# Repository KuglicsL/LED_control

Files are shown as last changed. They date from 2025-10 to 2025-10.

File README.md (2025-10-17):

# PWM & ARGB LED controller
ESP32 based controller for high-current PWM dimming and long-distance addressable LED driving
# Features
- 4x 12V fault-protected differential output digital channels for addressable LED strips
- 4x 30A 0-26V open-drain PWM channels for RGB(W) or single colour LED strips
- 4x isolated optocoupler inputs (0-50V) in two groups
- Onboard programmer using CP2102N USB-UART bridge
- Fused connections on all output power ports - ATO/ATC fuse holders
- Two pinheaders for analog inputs
- Small outline - 100x100mm
- Optional TVS diodes when assembled using cheaper transceivers
- Compatible with [the WLED project](https://kno.wled.ge/)
- You can find the gerbers, BOM, and PnP files in the Outputs folder if you want to manufacture your own!
  
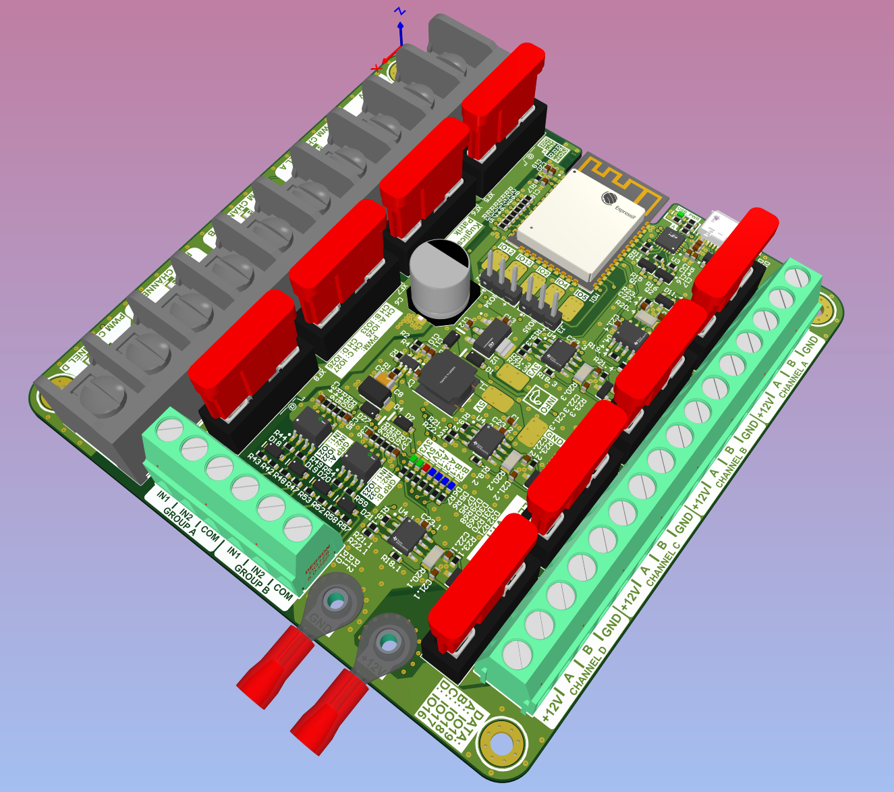
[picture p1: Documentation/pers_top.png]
PCB render


## PWM channels
The 4 independent PWM channels are open-drain outputs tested at 30A load. With adequate cooling, it can handle more. The FETs have TVS diodes, snubbers and flyback diodes protecting them.
## Digital channels
The 4 digital channels use THVD2450 transceivers for reliable long-distance addressable LED control. You can solder the in-line [receiver module](https://github.com/KuglicsL/Differential_receiver) to the LED strip at the first pixel.

## Limitations
The 12V input is routed to the digital channels, and the 24V input is for the PWM LED strips (voltage range 0-26V).
The control works from both the 12V and 24V inputs, however it needs the 12V input for the PWM gate drivers. **Without +12V connected, the PWM will not work.**

The differential outputs need a [receiver module](https://github.com/KuglicsL/Differential_receiver) on the LED side.

When using multiple channels at maximum current, the board probably needs cooling. I haven't got the time to test for exact numbers.

The USB-UART bridge IC needs to be configured to toggle the RX/TX leds - this is done with Silicon Labs' own tool. The whole USB-UART section could be replaced with a CH340 alternative for lower cost, but I wanted to use parts readily available from EU/NA distributors.

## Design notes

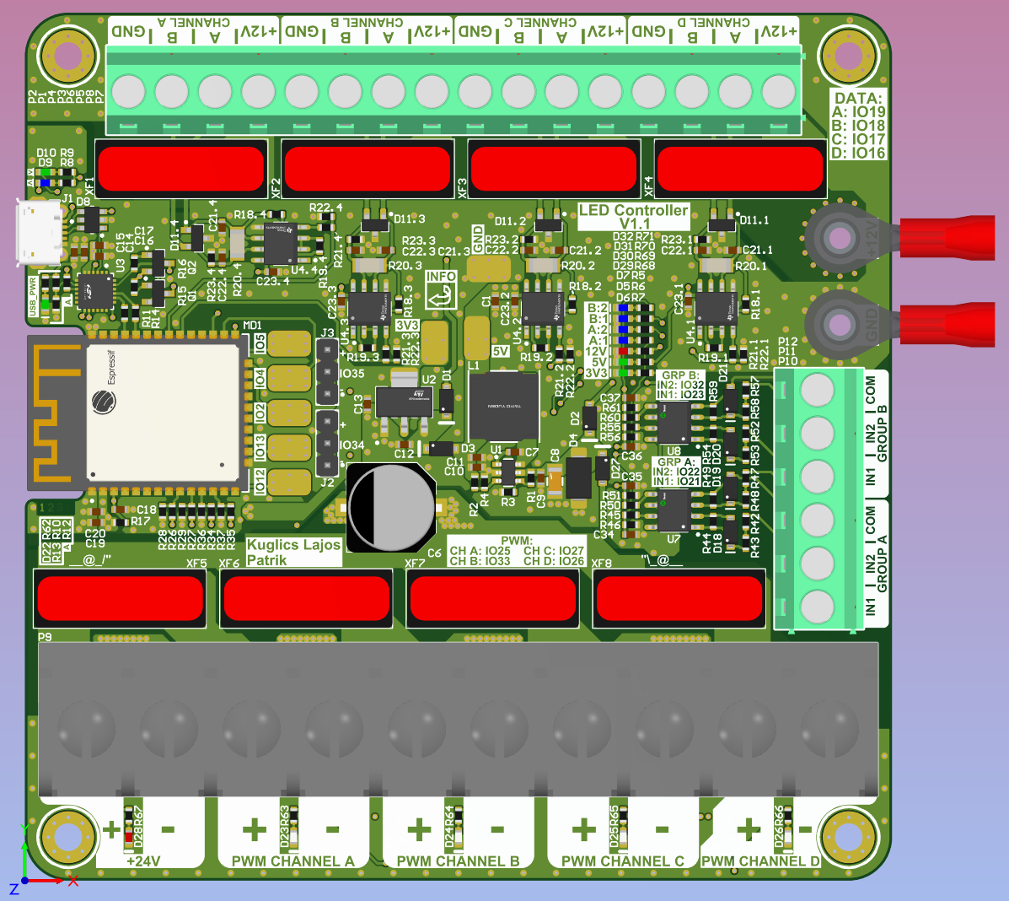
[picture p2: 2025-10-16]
Documentation/orth_front.png

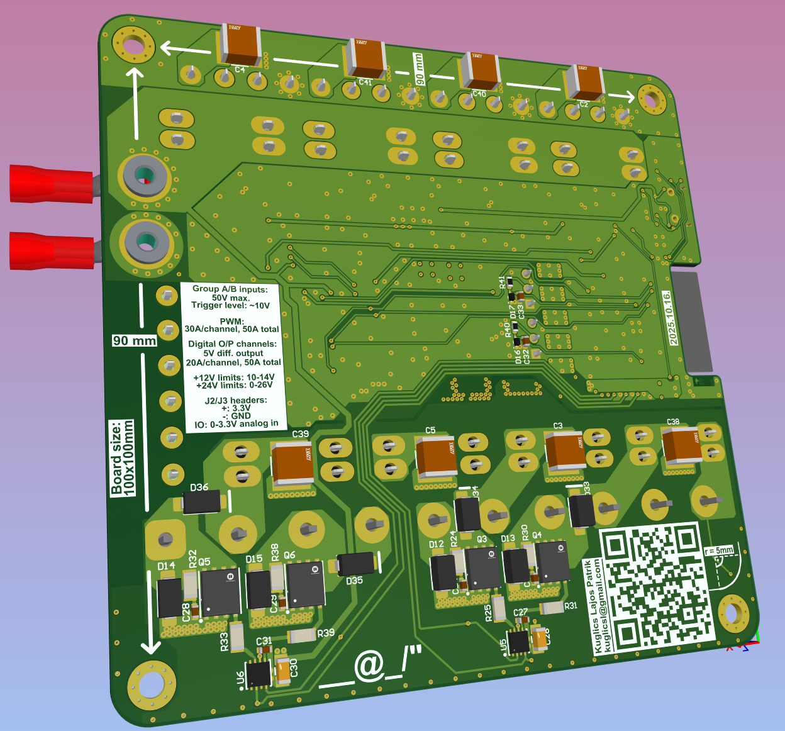
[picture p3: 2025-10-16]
Documentation/pers_back.png

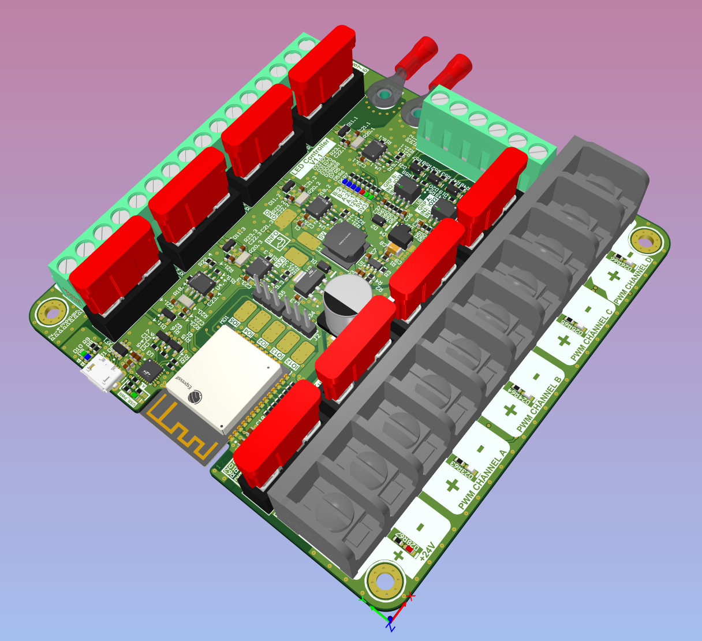
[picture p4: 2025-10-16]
Documentation/pers_bot.png

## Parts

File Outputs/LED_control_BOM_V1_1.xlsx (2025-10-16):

Comment | Description | Designator | Footprint | Pins | Quantity
ESP32-WROOM-32E (4MB) | RX TXRX MOD WIFI TRACE ANT SMD | MD1 | FP-ESP32-WROOM-32E_4MB-MFG | 39 | 1
CP2102N-A02-GQFN24 | IC USB TO UART BRIDGE QFN24 | U3 | FP-CP2102N-A02-GQFN24-MFG | 25 | 1
1050170001 | USB Connector, 5 Contact(s), Female, Right Angle, Surface Mount Terminal, Detent, Receptacle | J1 | USB-MICRO-B_V | 11 | 1
6PCV-10-006 | Barrier Strip Terminal Block, 25A, 1 Row(s), 1 Deck(s) | P9 | 6PCV-05-006-Footprint-1 | 10 | 1
IX4427MTR | 2 Channel Gate Driver IC, 4.5-30V, DFN-8 | U5, U6 | QFN65P300X300X85_HS-9N | 9 | 2
MOCD217M | Transistor Output Optocoupler, 2-Element, 2500V Isolation | U7, U8 | FP-751DZ-IPC_B | 8 | 2
THVD2450DR | Line Transceiver, 1 Func, 1 Driver, 1 Rcvr, PDSO8 | U4.1, U4.2, U4.3, U4.4 | FP-D0008A-IPC_B | 8 | 4
LMR54406DBVR | Switching Regulator, Current-mode, 0.6A, 1265kHz Switching Freq-Max, PDSO6 | U1 | SOT23-6 | 6 | 1
USBLC6-2SC6 | Trans Voltage Suppressor Diode, 5V V(RWM), Unidirectional, 1 Element, Silicon | D8 | STM-SOT23-6L_V | 6 | 1
BSC010N04LS6ATMA1 | OptiMOS 6 power MOSFET, 1.4mΩ max, 40V, 40A ID | Q3, Q4, Q5, Q6 | FP-483AE-MFG | 5 | 4
3557-10 | Keystone 3557-10 fuse holder; 3557-2 in RED | XF1, XF2, XF3, XF4, XF5, XF6, XF7, XF8 | Keystone 3557-2 | 4 | 8
LDL1117S33R | Fixed Positive LDO Regulator, 3.3V, 0.6V Dropout, PDSO4 | U2 | FP-SOT223-0046067-IPC_B | 4 | 1
BSS123,215 | Small Signal Field-Effect Transistor, 0.15A I(D), 100V, 1-Element, N-Channel, Silicon, Metal-oxide Semiconductor FET | Q1, Q2 | SOT23-3 | 3 | 2
NUP3105LT1G | Trans Voltage Suppressor Diode, 350W, 32V V(RWM), Bidirectional, 2 Element, Silicon | D11.1, D11.2, D11.3, D11.4 | SOT23-3 | 3 | 4
Pinheader 1x3 | Pinheader 1x3 | J2, J3 | FP-90120-0123-MFG | 3 | 2
1µF/50V/X5R | 0603 capacitor | C12 | C0603 | 2 | 1
1k/1%/0603 | 0603 1% resistor, 100mW | R12, R40, R41 | R0603 | 2 | 3
1N4148W | Rectifier Diode, 1 Phase, 1 Element, 0.15A, 75V V(RRM), Silicon | D18, D19, D20, D21 | SOD-123 | 2 | 4
1nF/50V/X7R | 0603 capacitor | C24, C25, C28, C29 | C0603 | 2 | 4
2R2/1%/1206 | 1206 1% resistor, 250mW | R24, R25, R30, R31, R32, R33, R38, R39 | RESC3216X70X50NL05T20 | 2 | 8
10µF/10V/X5R | 0603 capacitor | C1, C10, C11, C13, C14, C17, C19 | C0603 | 2 | 7
10k/1%/0603 | 0603 1% resistor, 100mW | R3, R4, R6, R7, R8, R9, R15, R16, R17, R18.1, R18.2, R18.3, R18.4, R19.1, R19.2, R19.3, R19.4, R22.1, R22.2, R22.3, R22.4, R23.1, R23.2, R23.3, R23.4, R28, R29, R36, R37, R42, R43, R44, R46, R47, R48, R49, R51, R52, R53, R54, R56, R57, R58, R59, R61, R62, R63, R64, R65, R66, R68, R69, R70, R71 | R0603 | 2 | 54
10pF/50V/NPO | 0603 capacitor | C21.1, C21.2, C21.3, C21.4, C22.1, C22.2, C22.3, C22.4 | C0603 | 2 | 8
22k/1%/0603 | 0603 1% resistor, 100mW | R10 | R0603 | 2 | 1
53.6k/1%/0603 | 0603 1% resistor, 100mW | R1, R2, R5, R13, R67 | R0603 | 2 | 5
100/1%/0603 | 0603 1% resistor, 100mW | R11, R14, R21.1, R21.2, R21.3, R21.4, R26, R27, R34, R35, R45, R50, R55, R60 | R0603 | 2 | 14
100nF/50V/X7R | 0603 capacitor | C7, C9, C15, C16, C18, C20, C23.1, C23.2, C23.3, C23.4, C27, C31, C32, C33, C34, C35, C36, C37 | C0603 | 2 | 18
120R/1%/1206 | 1206 1% resistor, 250mW | R20.1, R20.2, R20.3, R20.4 | RESC3216X70X50NL05T20 | 2 | 4
22201C106MAT2A | Ceramic Capacitor, Multilayer, Ceramic, 100V, 20% +Tol, 20% -Tol, X7R, 15% TC, 10uF, Surface Mount, 2220 | C2, C3, C4, C5, C38, C39, C40, C41 | FP-2220-L_5_7_0_5-W_5_0_4-IPC_B | 2 | 8
CL31B105KBHNNNE | Ceramic Capacitor, Multilayer, Ceramic, 50V, 10% +Tol, 10% -Tol, X7R, 15% TC, 1uF, Surface Mount, 1206 | C26, C30 | CL31-1.6mm | 2 | 2
CL31B106KBHNNNE | Ceramic Capacitor, Multilayer, Ceramic, 50V, 10% +Tol, 10% -Tol, X7R, 15% TC, 10uF, Surface Mount, 1206 | C8 | CL31-1.6mm | 2 | 1
DG128-5.0-02P-14-00AH | Degson DG128-5.0-02P-14-00AH 2-Way PCB Screw Terminal Block 5.0mm Green | P1, P2, P3, P4, P5, P6, P7, P8, P10, P11, P12 | Sorkapocs_5mm | 2 | 11
EEH-ZA1V271P | Aluminum Electrolytic Capacitor, Polarized, Aluminum (solid Polymer), 35V, 20% +Tol, 20% -Tol, 270uF, Surface Mount, 4141 | C6 | CPOL_10x10.2MM | 2 | 1
ESD321DYAR | 0.9pF 3.6V ±30kV ESD protection diode with 6.8V 16A TLP clamping for USB 2.0 2-SOT-5X3 -55 to 150 | D16, D17 | SOD-523_ANODE_MARK | 2 | 2
KPG-1608ZGC | Single Color LED, Green, Water Clear, 1.2mm | D5, D6, D10, D22 | LED0603_GREEN | 2 | 4
LSQ976-NR-1 | Single Color LED, Super Red, Colorless Diffused, 1mm | D7, D28 | LED0603_RED | 2 | 2
LTW-C191TS5 | Single Color LED, White, 1.1mm, 45-180mcd, 2.7-3.15V Vf | D23, D24, D25, D26 | LED0603_WHITE | 2 | 4
MBR160 | Rectifier Diode, Schottky, 1 Element, 1A, 60V, Silicon, SOD-123 | D1, D2, D3, D27 | SOD-123 | 2 | 4
NRS8040T220MJGJ | General Purpose Inductor, 22uH, 20%, 1 Element, SMD, 3131 | L1 | FP-NR8040-H_4_0-MFG | 2 | 1
SK34SMA-3G | Rectifier Diode, Schottky, 1 Phase, 1 Element, 3A, 40V V(RRM), Silicon, DO-214AC (SMA) | D33, D34, D35, D36 | DO-214AC(SMA) | 2 | 4
SMAJ30CA | Trans Voltage Suppressor Diode, 400W, 30V V(RWM), Bidirectional, 1 Element, Silicon, DO-214AC | D4, D12, D13, D14, D15 | DO-214AC(SMA) | 2 | 5
SR190BC-B4-1BJ | 0603 blue LED, 200-400mcd, 3.2V@20mA | D9, D29, D30, D31, D32 | LED0603_BLUE | 2 | 5
9775031360R | WA-SMSR SMT Steel Spacer Reverse, M3 x 3.1mm | MP3, MP6 | 9775031360 | 1 | 2

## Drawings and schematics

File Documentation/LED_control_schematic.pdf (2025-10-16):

# USB_Programmer.SchDoc IO⁰ EN CP_RX CP_TX

# P1 DG¹²⁸⁻⁵.0⁻02P⁻¹⁴⁻⁰⁰AH 12

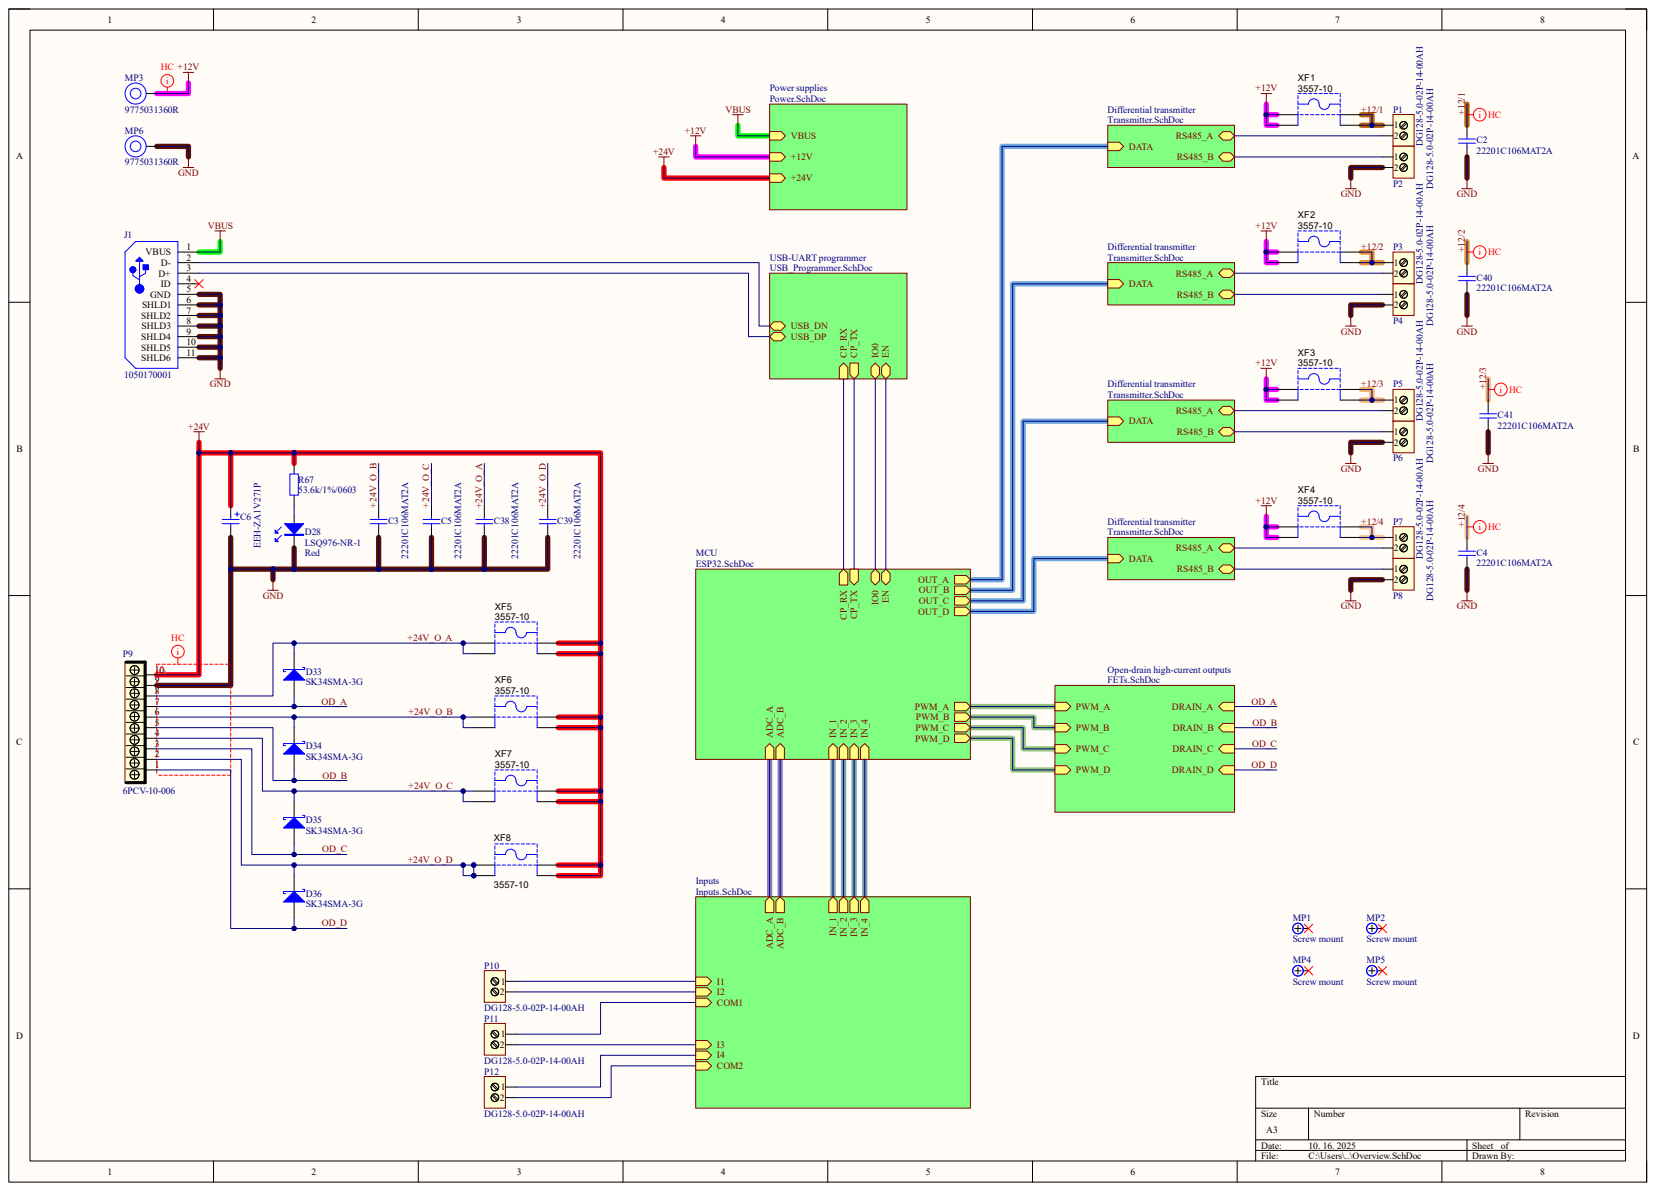
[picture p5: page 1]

Open-drain high-current outputs
FETs.SchDoc

## Ven_min = 7.0V

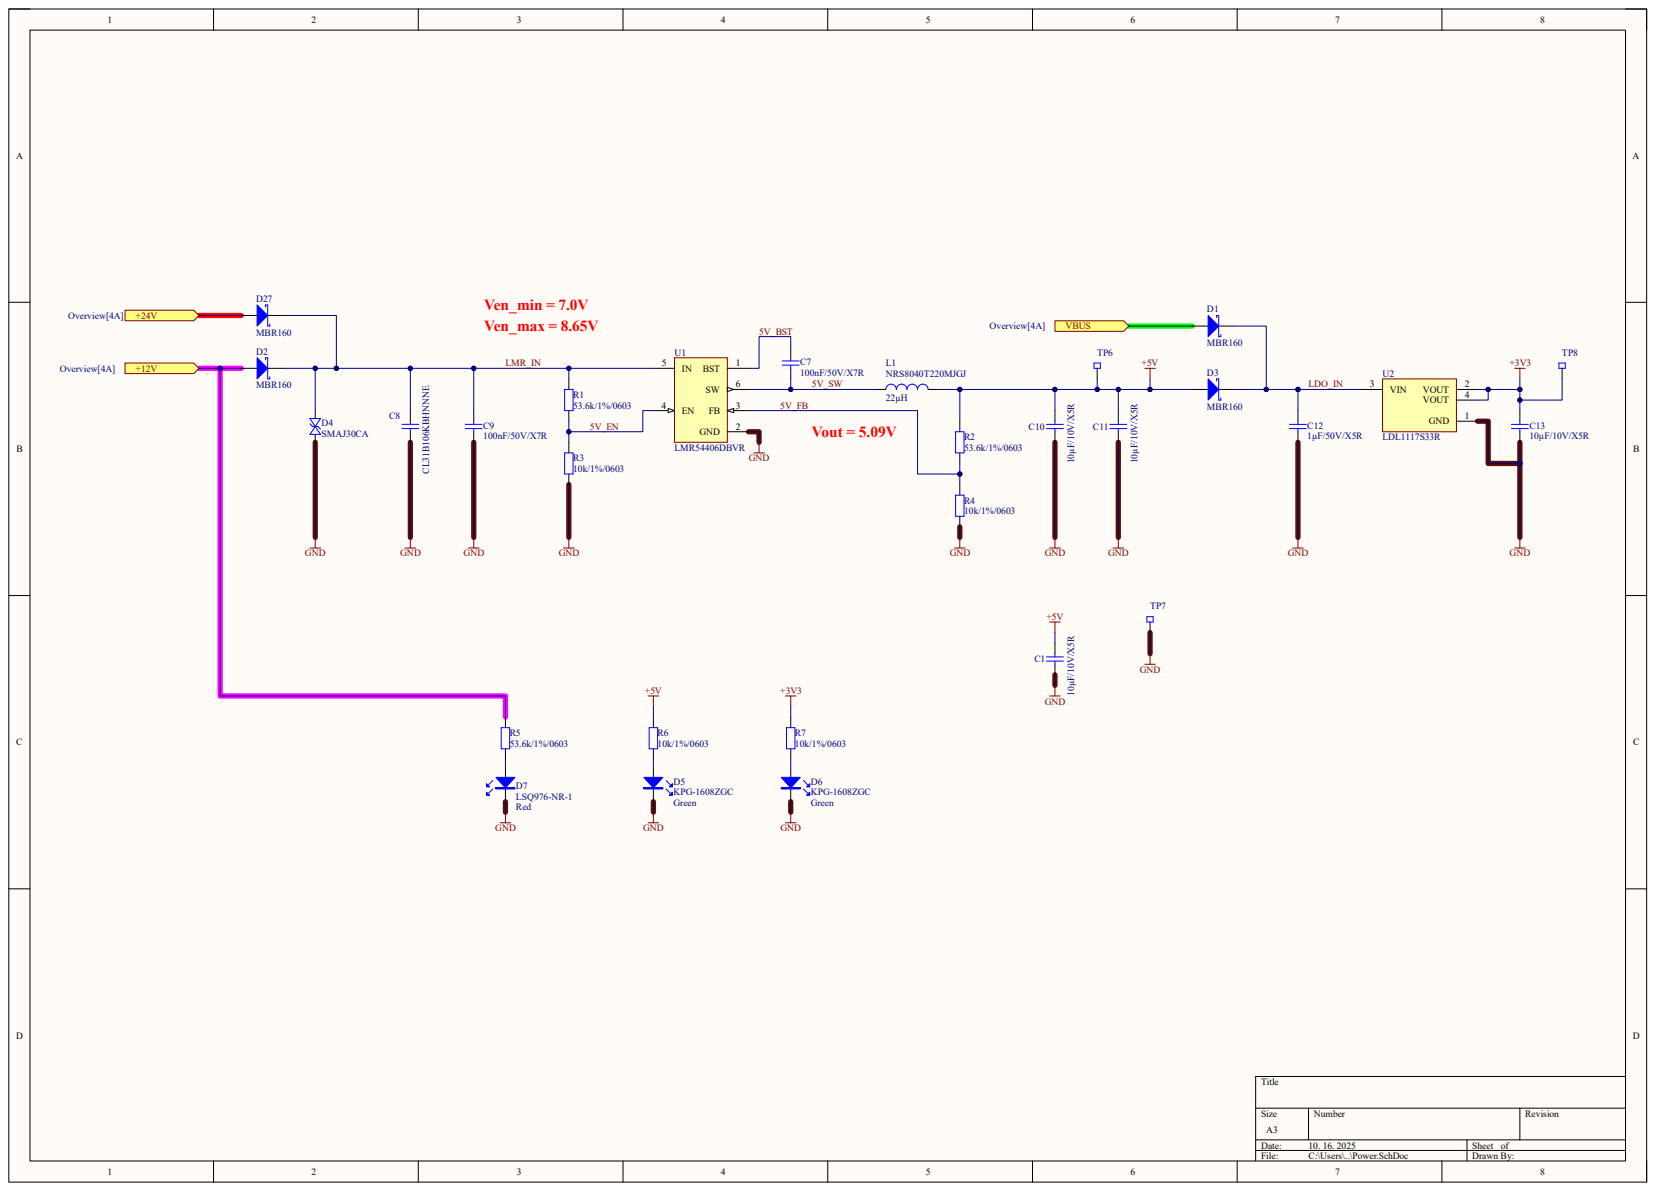
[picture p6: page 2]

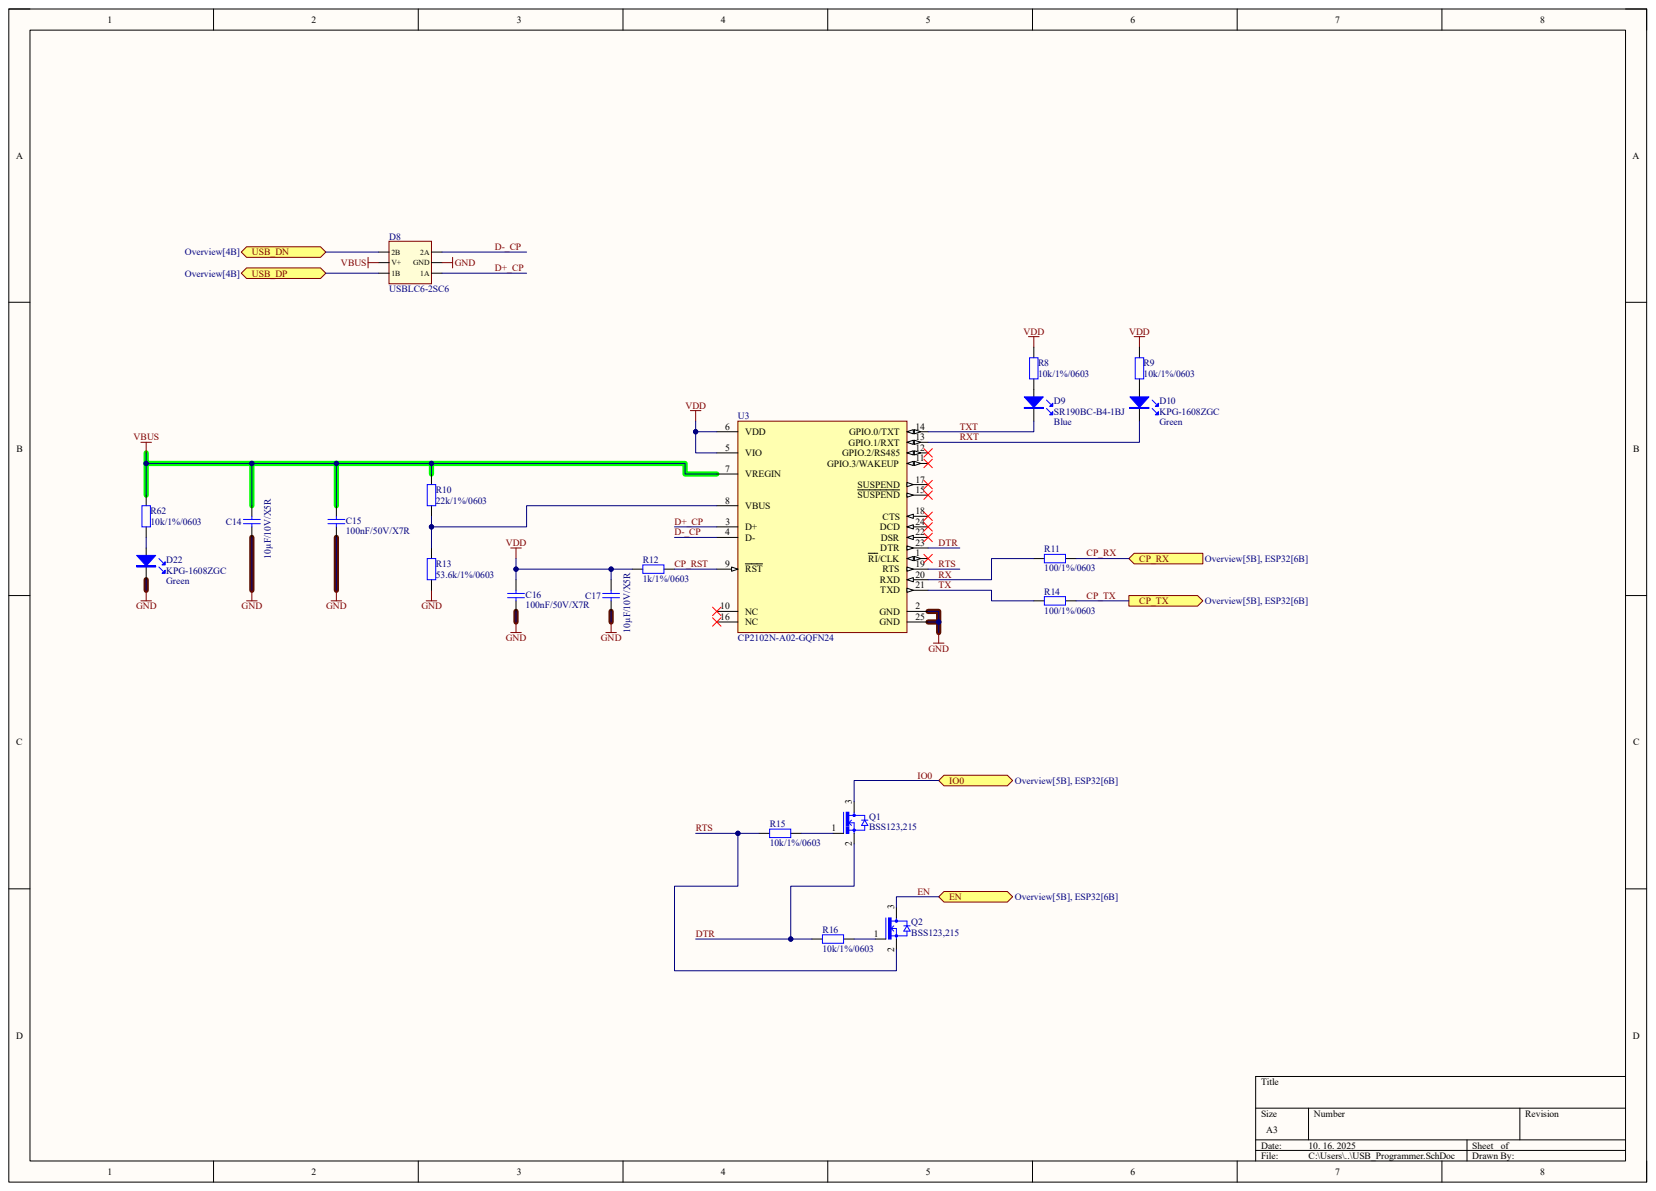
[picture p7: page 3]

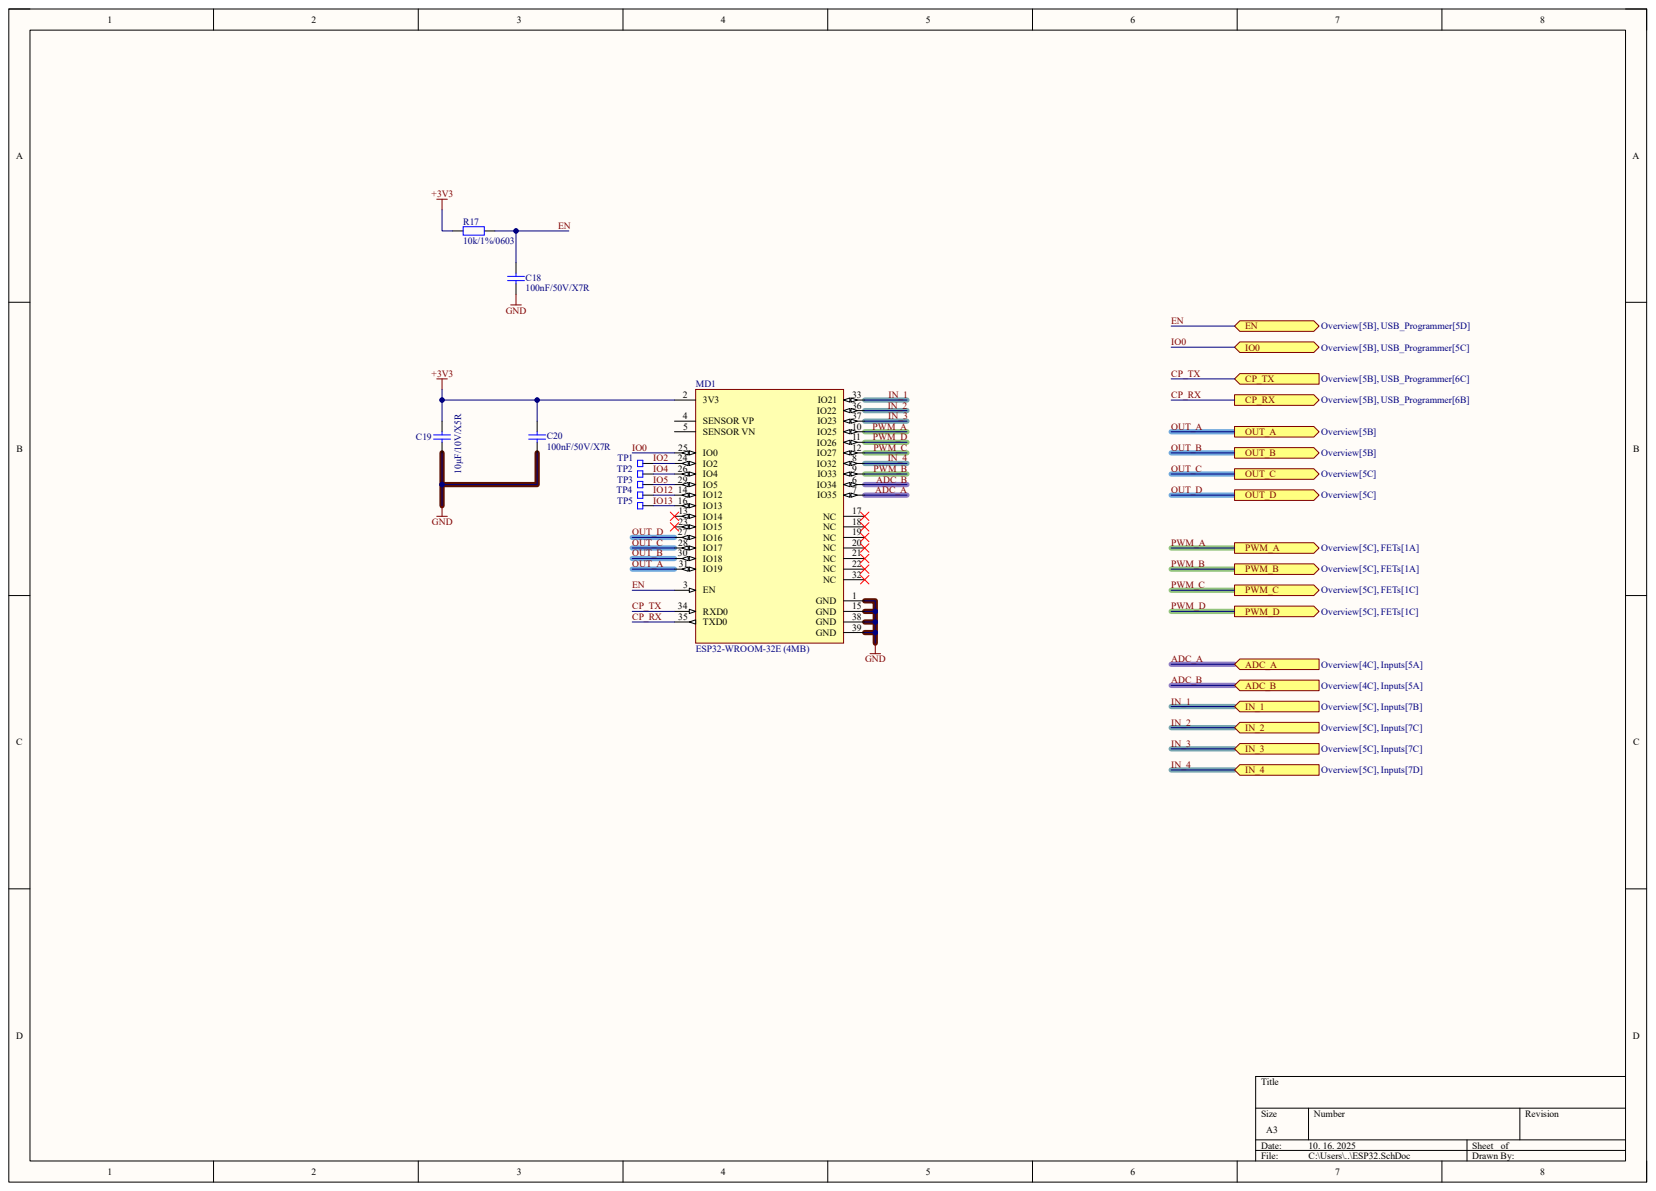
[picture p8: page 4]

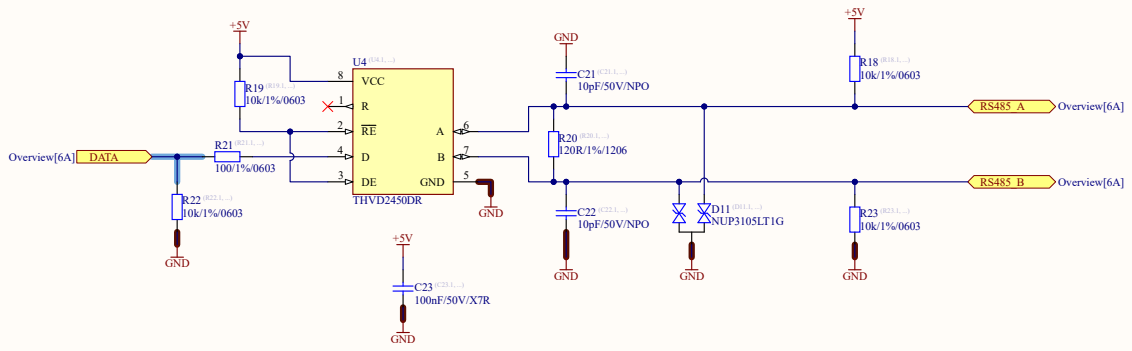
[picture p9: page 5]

A A

### INA 2

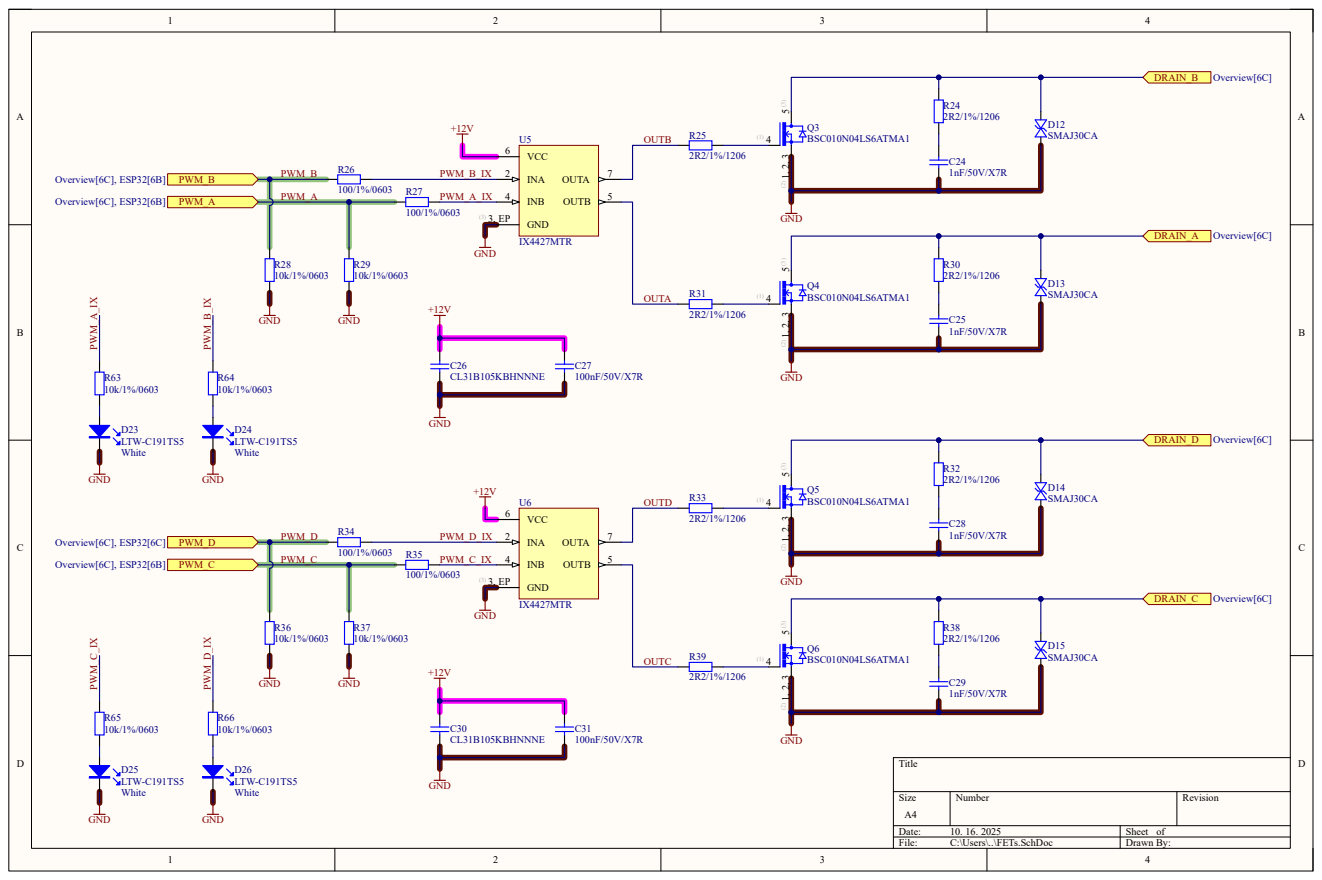
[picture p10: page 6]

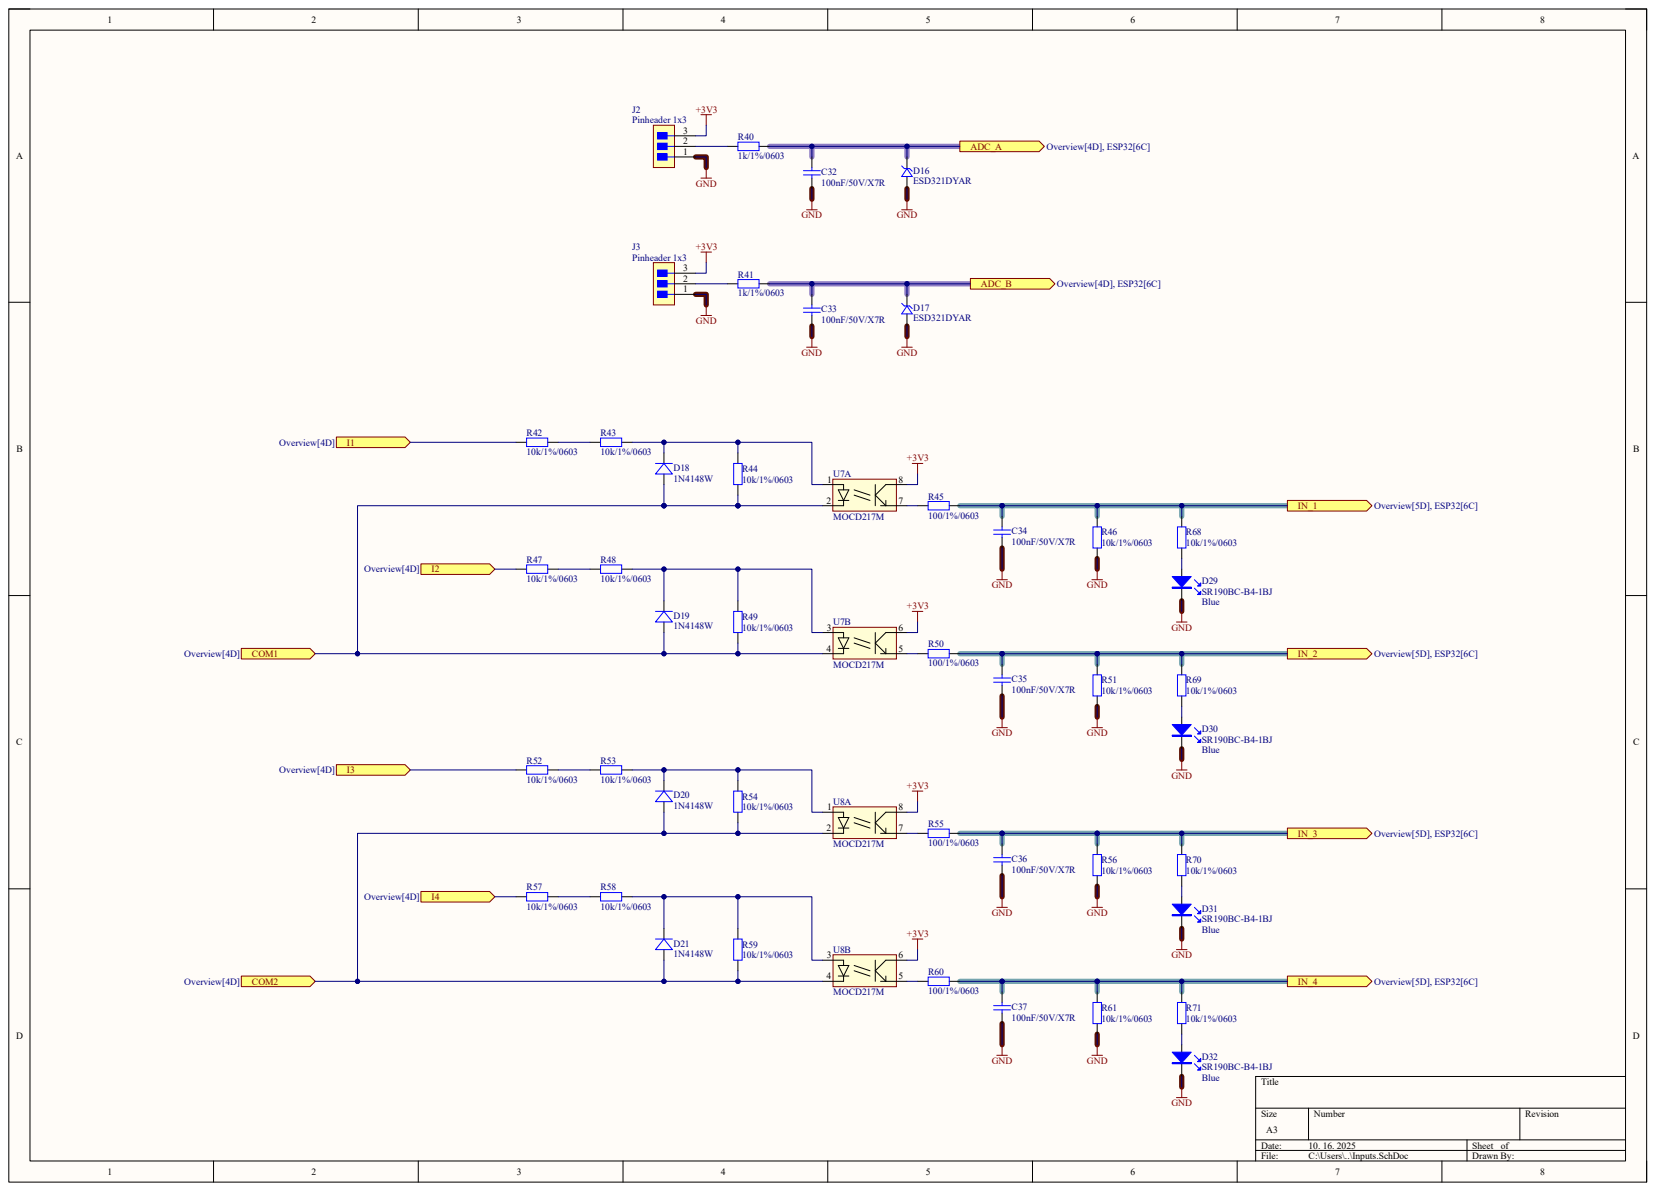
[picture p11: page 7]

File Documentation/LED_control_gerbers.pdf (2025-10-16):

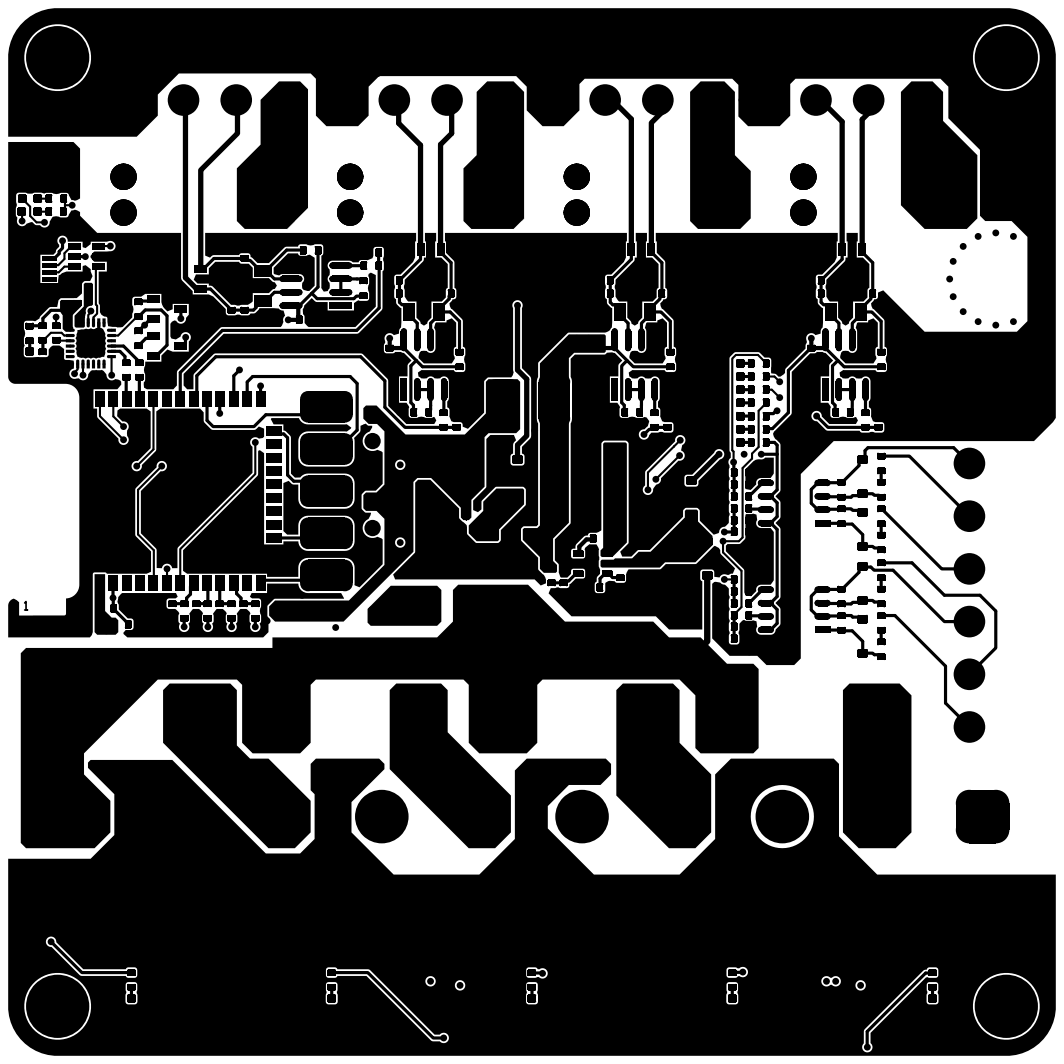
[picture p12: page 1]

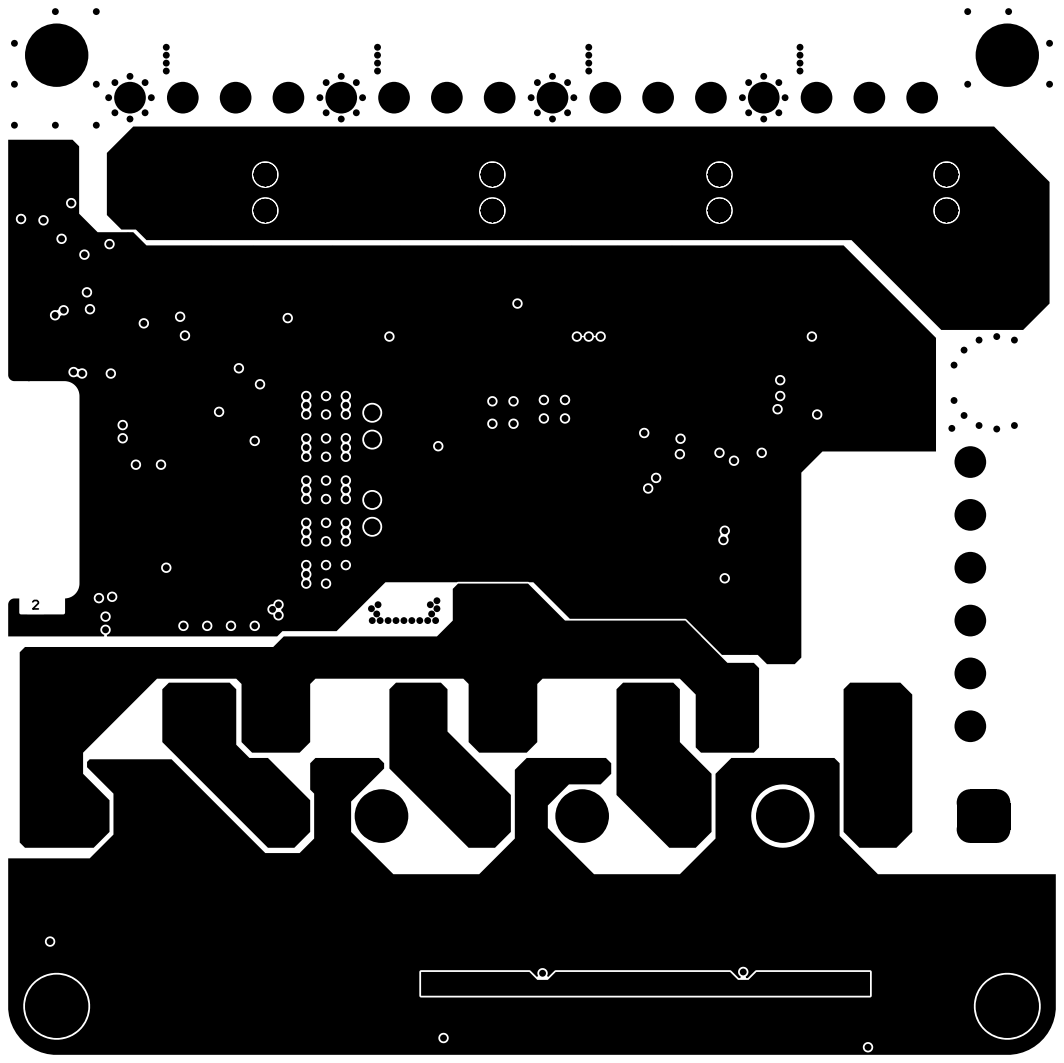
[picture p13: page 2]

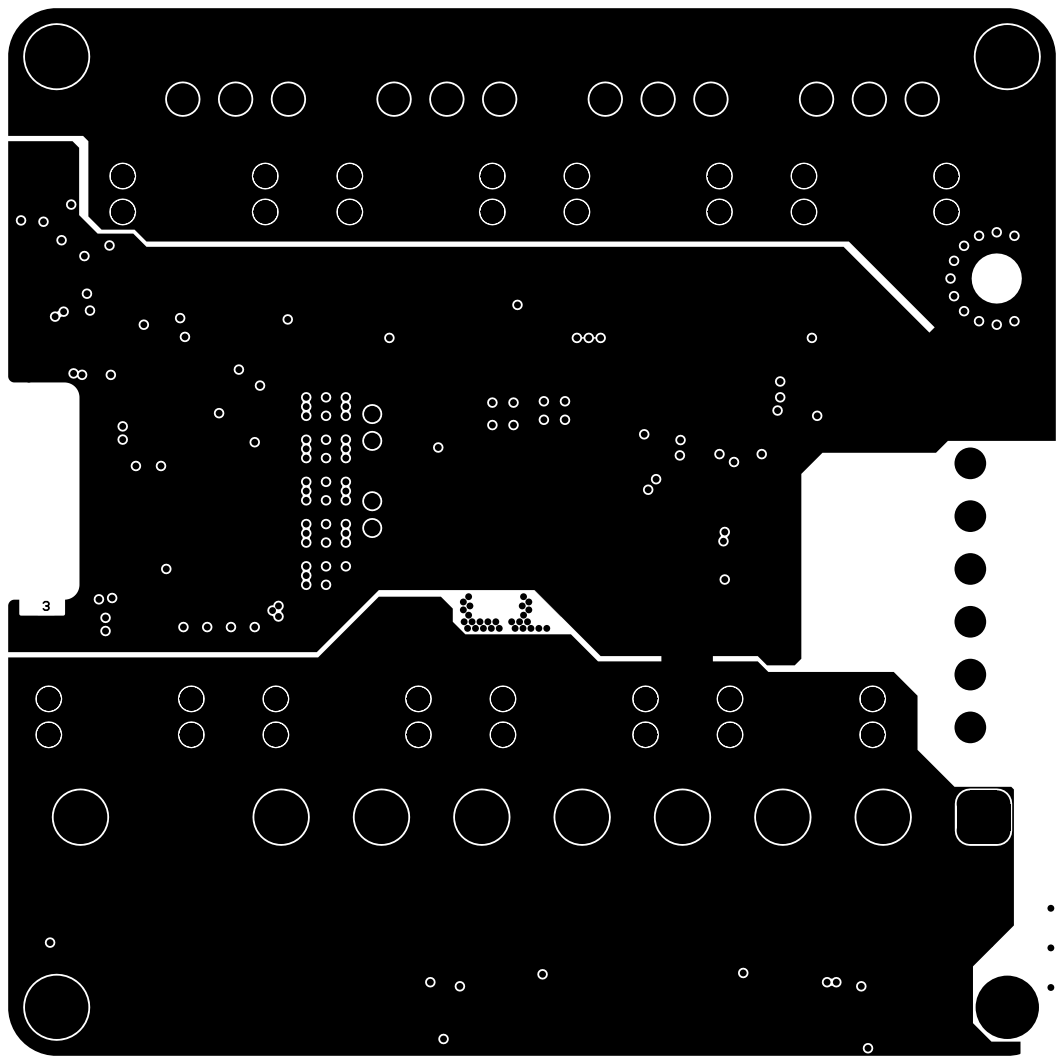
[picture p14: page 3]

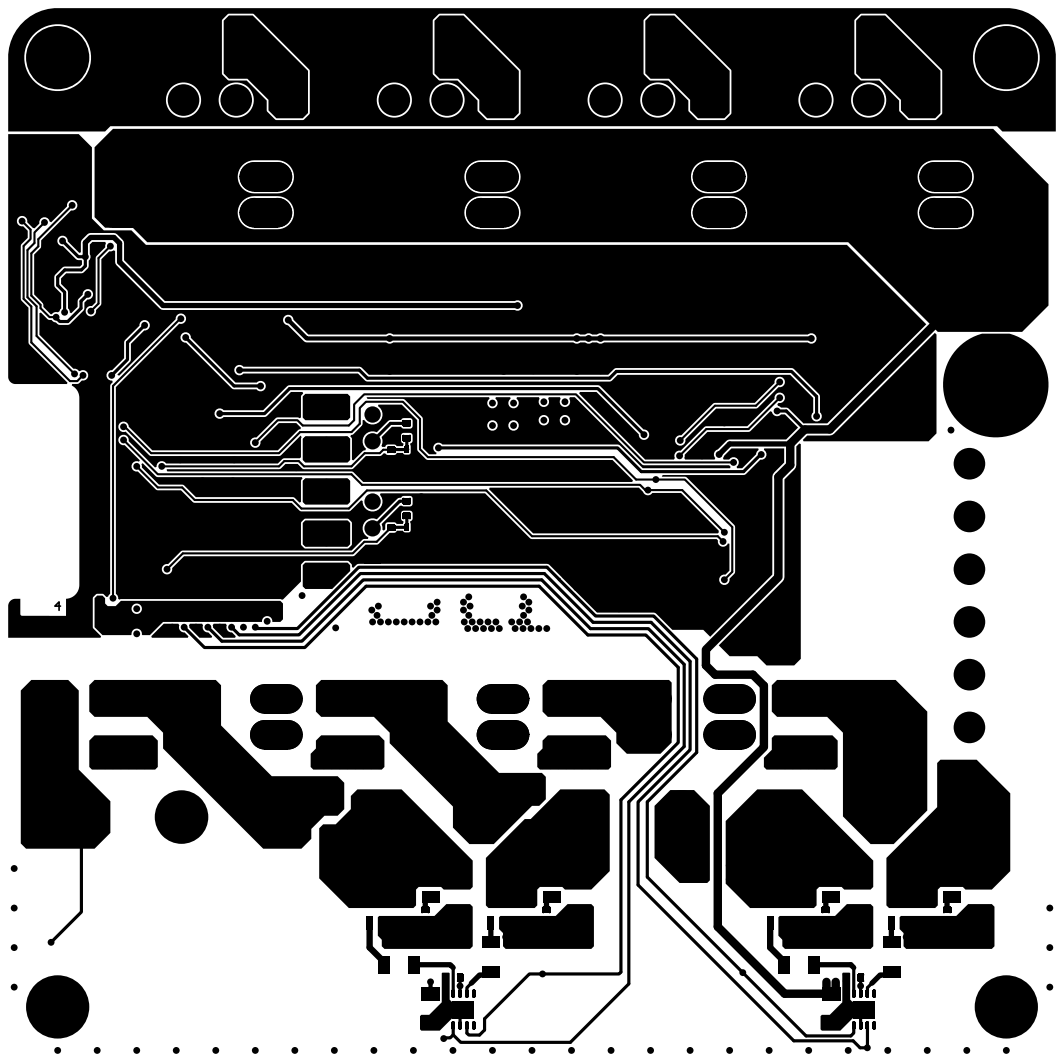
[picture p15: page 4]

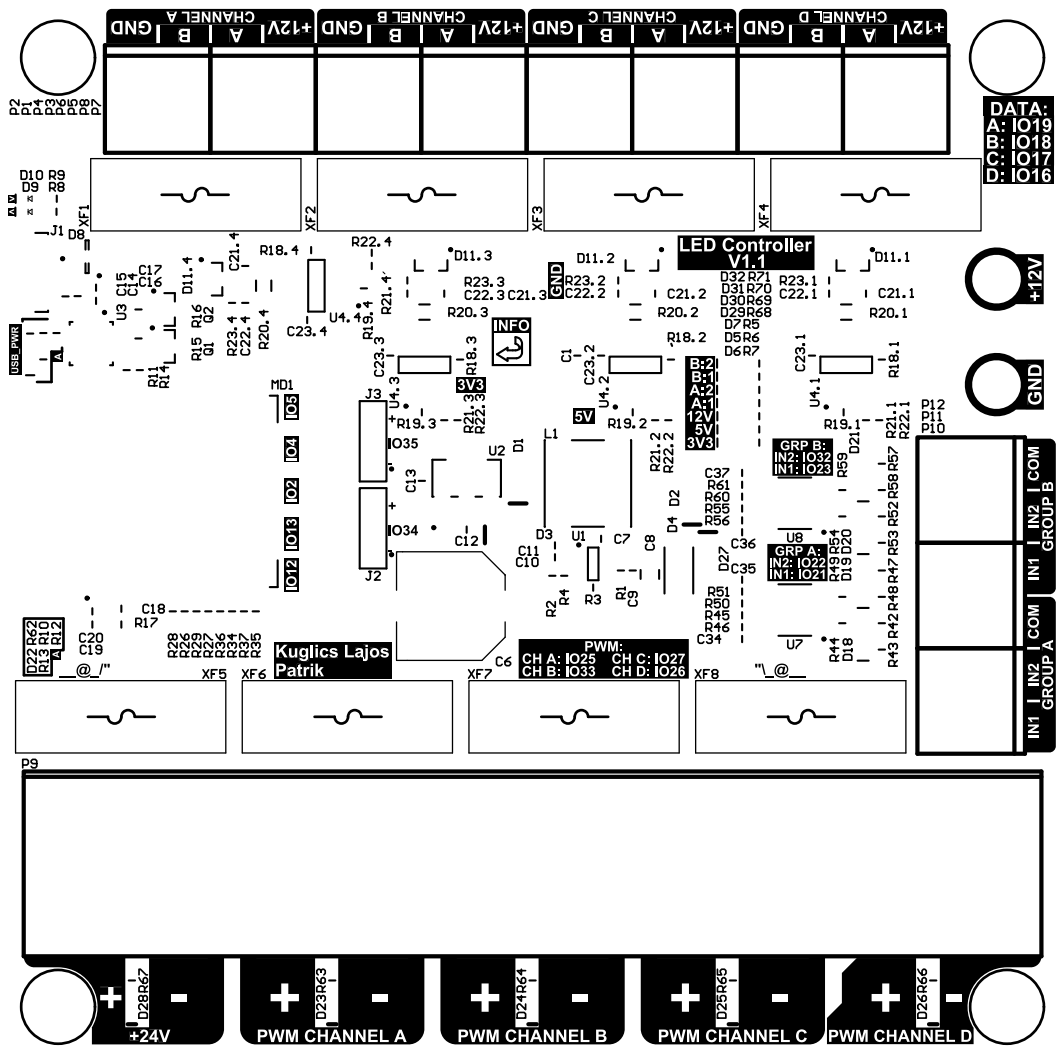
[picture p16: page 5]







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
